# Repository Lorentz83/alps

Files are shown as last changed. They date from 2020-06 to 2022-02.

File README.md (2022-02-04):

# Another Light Painting Stick (ALPS)

This is just another programmable light painting stick.

But, compared to the other projects I've seen so far, instead of
storing all the settings on an SD card you can program the stick from
the phone.

WARNING: this is a work in progress and documentation may be not
         aligned with the current status of the code.

## TODO

An unordered list of stuff I'd like to work on:

- documentation:
  - add some example photos;
- on the board side:
  - re-add/improve SD card support;
- on the Android side:
  - re-design the whole app UI/UX (any help is appreciated);
  - add gradient/pattern generators;
  - write some unit test;

And most important:
- take many photos, enjoy the time spent, and find new features to implement :)

## Hardware

The following links are **not** affiliated. What follows is just a
list of stuff I bought and paid out of my pocket (well, technically
the Arduino was a birthday present from friends, but you know what I
mean).

For sure there are alternative products I'm not aware. If you know any
that may work better, please let me know.

- USB power bank;
- [Adafruit NeoPixel](https://learn.adafruit.com/adafruit-neopixel-uberguide/)
  144 LEDs 1 meter strip;
- HC-05 or HC-06 Bluetooth module;
- a capacitor between 500 and 1000 µF at 6.3 Volts or higher[^1];
- a resistor between 300 to 500 Ohm[^1];
- some USB cable to salvage;
- (Arduino Mega ADK)[https://docs.arduino.cc/retired/boards/arduino-mega-adk-rev3]
  or equivalent;
  - 1K resistor;
  - 2K resistor;
- or (Teensy 4.0)[https://www.pjrc.com/store/teensy40.html] which is
  more expensive than Arduino but faster.
  - [74AHCT125 quad level shifter](https://www.adafruit.com/product/1787)

I power everything using a 10400mAh USB power bank. There are a couple
of issues to keep in mind when using USB power banks for this project:

1. some power banks may disconnect the power if they see that there is
   too little usage (in other words, when the LED strip is off);
2. USB power banks usually limits the current at 2A (following the USB
   standard). At full brightness white, 144 NeoPixels consumes more
   than 8A[^1]. In practice that's probably too much light if you want
   to light paint.

More experiments using lithium batteries are needed, the power bank
has the benefit of simplicity because it doesn't require any voltage
regulator.

On the board side, not a lot of connectors are required. I suspect
that pretty much any programmable microcontroller could work as long
as you can load Arduino code on it.

My only suggestion is to be sure that it has at least a second
hardware serial to connect the bluetooth module.
It is not strictly required, but having the USB serial free is useful
to write debug messages, and I noticed that the software serial
library is usually not reliable enough for this project.

About the bluetooth module, the HC-05 may be faster (but if you can
find a good datasheet to prove it please let me know). But since we
don't need master mode the HC-06 can be good enough.

About the NeoPixels, I use the 144 LED for 1 meter. It is possible to
get less dense strips, but the result is much more pixelated.
Some code change is required if you want to support more than 144 LEDs.

The connections are pretty easy, but there are serious differences
between using Arduino or Teensy because Arduino is a 5V board while
Teensy is a 3v board.

WARNING: In both the cases the LED strip **cannot** be powered from
         the board because it drains far too much current.  If you
         power the board from a different source (for example the
         computer, when you connect it to load new code), it is
         important to share the ground. Also, don't put current on the
         NeoPixel data pin unless the NeoPixel is powered too[^1].
         In doubt, always disconnect the extra power and the whole LED
         strip while connecting the board to the computer.

The capacitor is used to smooth current peaks, according to the
NeoPixel guide[^1] it is mostly required if you power it from a bench
transformer, but it doesn't hurt to keep it there in any case to give
the extra power in case of brief spikes.

The resistor on the NeoPixel data pin should protect the 1st
pixel[^1]. It should be as close as the LED as possible.

TX and RX pin between the bluetooth module and the board are crossed
because the transmission of one goes to the receiving pin of the
other.

### Arduino

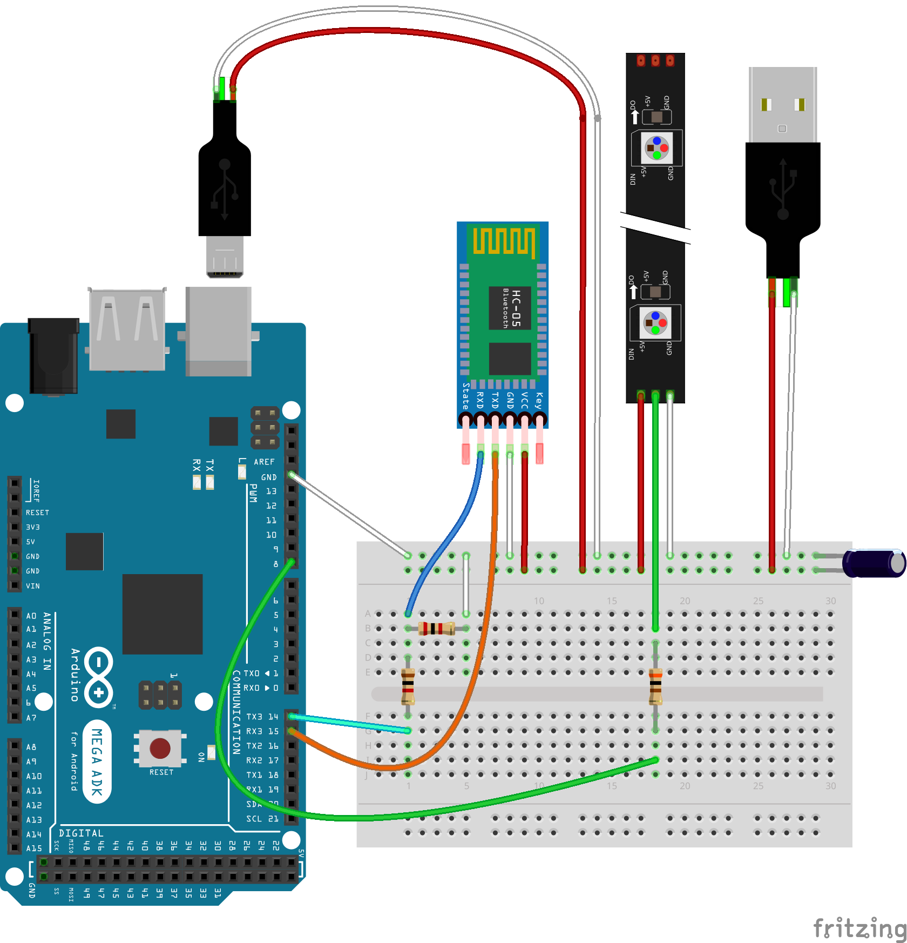
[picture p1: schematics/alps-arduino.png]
schematic


Arduino can be powered with 5V only from the USB cable, here it is
good if you have an old cable around to cut.

Remember that the bluetooth module data pin is 3.3V only. Therefore
you need the 2 resistors to lower down the 5V arduino output. The 1K
resistor between the arduino TX pin and the bluetooth RX pin, and the
2K resistor between the bluetooth RX pin and the ground.

The cable between the ground pin and the ground power is not required
in this configuration because the ground is already connected through
the USB cable.
But it is required if you power the board from the computer while the
LED strip is powered from the battery. Since this extra connection
doesn't hurt in any case, I strongly suggest to keep it always in
place.

### Teensy 4.0

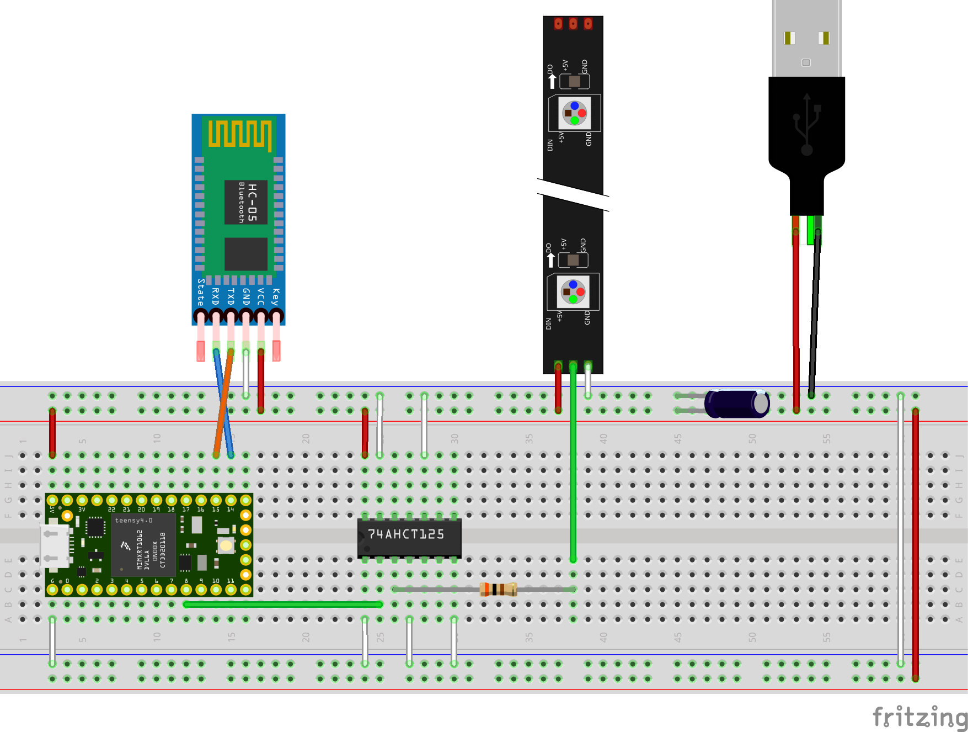
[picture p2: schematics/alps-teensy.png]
schematic


Being a 3V board, the Teensy can be powered from 5V through the 5V
pin.

WARNING: remember to remove the cable to the 5v pin if you connect the
         Teensy via USB to the computer while the LED are
         powered. Otherwise you may damage your computer.

The 74AHCT125 is used to send 5V signals to the NeoPixel data pin from
the 3V output. It is not always required, according to many websites
newer LED strips works with a 3V input too. But I noticed some
glitches without it, especially using the FastLED library.

Most of the connections around the 74AHCT125 are required only because
"all unused inputs of the device must be held at VCC or GND to ensure
proper device operation"[^2].

[^1]: https://learn.adafruit.com/adafruit-neopixel-uberguide/powering-neopixels
[^2]: https://www.ti.com/lit/ds/symlink/sn74ahct125.pdf

## License

This program is free software. The code I wrote is under GPL but some
of it depends on libraries under different (but compatible) license.
In doubt check the header of the specific files.

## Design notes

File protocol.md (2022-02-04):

# Protocol

Let's try do document a little the communication protocol between the
host (currently the Android app) and the client (the stick,
implemented by the Arduino or Teensy).
So that I can capture some of the design choiche and avoid reverse
engineering it next time I need to change it.

Requirements:
- Live show, sending a image and display it in real time;
- Info, to validate the software version;
- Reset, to re-synchronize the protocol;

Nice to have:
- Upload, send an image to the internal memory;
- Reshow, display an image from the internal memory;
- Reshow settings, to change brightness, delay, and loop option of the
  reshow;

In V1 the maximum image size I ever experimented with was 868x144;

WARNING: I don't plan to bump version numbers until I feel that the
         software is out of beta.

## V2

Protocol limitation:
- the number of LEDs must fit into a byte (255 max)
- the number of columns we can transfer in a single message must fit
  into a byte too.
- there is no escape sequence, if some bytes are lost the host needs
  to attempt to re-synchronize the communication before suggesting to
  turn off and on the client again.

All messages are initiated by the host. The host must wait for the
answer (or a reasonable timeout) before sending a new message.

The client can either acknowledge the message or return an error.
Both messages are 5 bytes long.

The acknowledgment message (ack in the future) is:
- ascii 'o', as in ok.
- 4 bytes of crc32 in little endian (least significant byte first).

The crc32 includes everything starting from the last message
identifier sent from the host.

The error message (nack in the future) is:
- ascii 'k', as in ko.
- 4 bytes to identify the error.

Before generating the error the stick should discard all the incoming
data over the wire. This is because, without having an escape
sequence, we cannot distinguish a valid message marker by a random
pixel color.

The plan is to document the error codes in the Arduino code in a
machine parsable, and write a script to extract them and generate a
map consumable by java. I didn't reach this point yet.

The client generates an error if it gets an invalid message marker, or
a message that is invalid for the current internal status.

### Host initiated messages

*info*

This is the only message that doesn't get an ack or a nack as answer.
It should be used when the connection is established so that host and
client can agree on the protocol version and exchange information
about the hardware.

The host sends a single byte '?'.

The client answers with 5 bytes:
0. the ascii '!'
1. a byte that should be interpreted as a bitset which describes the
   features enabled (so far nothing is supported, the idea is to use a
   bit to define if the stick has an SD card).
2. reserved for future use, shouldn't be validated by this version of
   the protocol.
3. the number of LEDs in the stick (unsigned int).
4. the maximum number of columns we can send in a single message
   (unsigned int).

The host should disconnect and raise an error message if it doesn't
support this version or doesn't recognize the message.

*new image*

It is used to start sending a new image for a live show.

The host sends the following bytes:
0. the ascii 'n' as in new image.
1. the number of pixels per column (unsigned int).
2. the delay in ms before showing the next column (unsigned int).
3. the number of columns sent in this message (must be at maximum what
   returned by info).
3. the pixels data in RGB (one byte per channel), for a total of
   columns * pixels * 3 bytes.

When a column is received the client takes care of rendering it.  It
should also take care of the delay as best effort (too much precision
is impossible because of delays in bluetooth communication and
slowness in updating the LEDs).

When all the data is received, and all the columns have been drawn on
the stick, the client sends the ack.
The host should verify the crc returned and raise an error if they
don't match.

The client can send a nack in case of validation errors of the header
data (example: too many pixels or columns) or if the data is not
received after a certain amount of time (currently 1 second, the
default timeout of Arduino read).

*continue image*

It is used to send the next batch of columns of an image.

The host sends:
0. the ascii 'c' as in continue.
1. lastMessage, a byte that evaluates to false if this is the last
   message for this image.
2. the number of columns to be sent (0 is a valid value).
3. pixels color in the same format as new image.

The client handles this message as the new image.

The only difference is that, if lastMessage is set to true, after
rendering the last column it waits the delay and turns off the stick.

*off*

Aborts the current operation and turns off the stick.
It can be used to re-sync the protocol in case an error happens.

The host sends:
- the ascii 'o' as in off.
- 4 random bytes.

The client answers with an ack.

If the host receives a nack or the crc returned doesn't match, the
host can assume some old message was on the wire and therefore can
retry sending another off.
Since the client must flush the buffer every time an error is
returned, the 2 should be able to re-sync eventually.

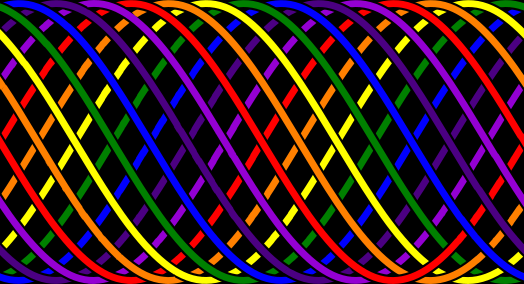
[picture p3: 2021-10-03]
resources/helix.png

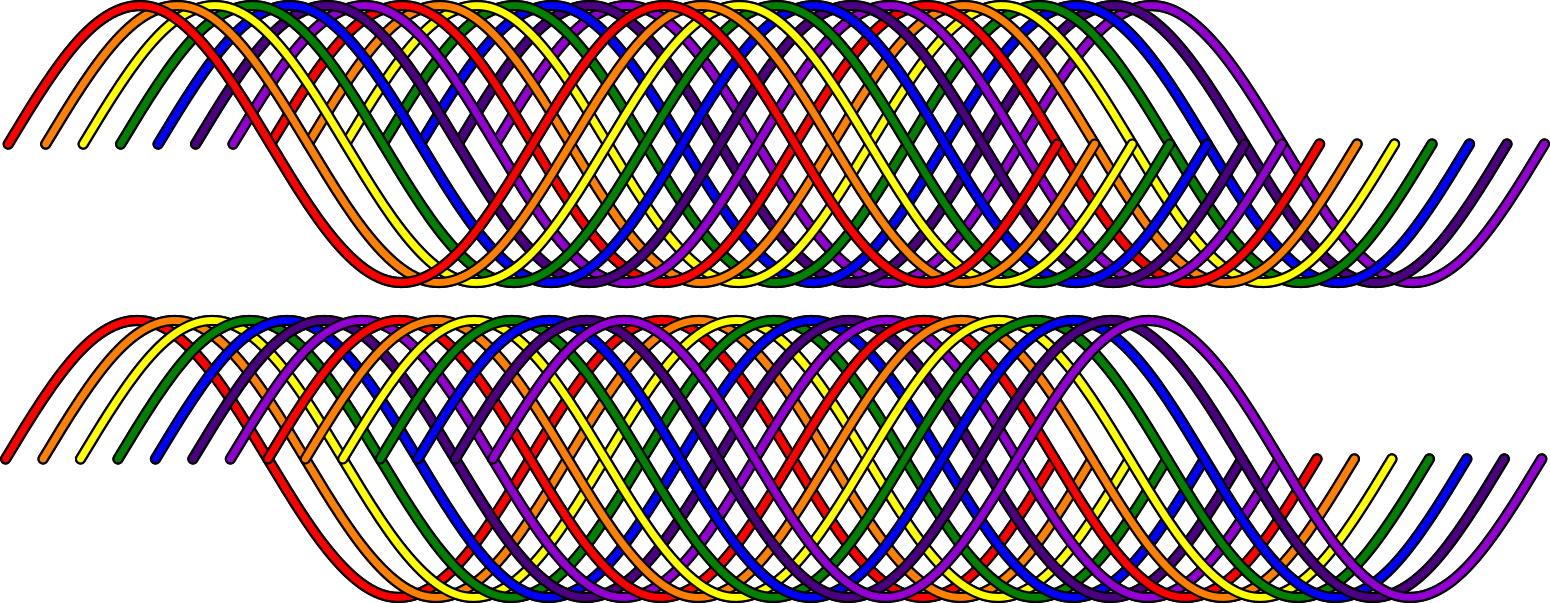
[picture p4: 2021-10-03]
resources/g3083.png

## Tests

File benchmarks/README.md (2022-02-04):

# Benchmarks

This directory contains a few benchmarks.

1. `ledspeed` measures how fast are different libraries in sending
   pixels.
2. `serialread` and `serialwrite` work in parallel to test the
   bluetooth connection.

NOTE: everything here is more like a scrapbook for me than an actual
product, to run the tests you have likely to touch the code to enable
some specific behaviours.  I tried to leave as many comments as
possible, but I may have failed.

## Findings

### LED libraries

Theoretically

> WS2812 strips are slow for writing data, with a data rate of just
> 800khz, it takes 30µs to write out a single led's worth of data[^1]

and they also need 300us reset time to wait after the whole strip is
written.[^2]

[^1]: https://github.com/FastLED/FastLED/wiki/Parallel-Output
[^2]: https://github.com/PaulStoffregen/WS2812Serial/issues/4

Therefore these are hard limits:
 - 4.32 milliseconds for a column, without wait (144 pixels)
 - 665 milliseconds for a square (144x144)
 - 1.3 seconds for a wide image (288x144)

In the `ledspeed` test, we simulate sending 10 times a 144x144 pixels
image, therefore the best we could get from this benchmark is 6.65
seconds, which is pretty much what we see with adafruit and DMA using
Tennsy 4.

NOTE: in this kind of tests we cannot measure the time on arduino
because `millis()` is not incremented when interrupts are disabled
([ref](https://forum.arduino.cc/t/does-nointerrupts-disable-the-millisecond-timer/433292/9)).

It is still interesting to measure it because it gives us an
estimation of how much time is spent in not sending data, which should
be processing and waiting to reset.

The 3 libraries compared are:
1. [Adafruit_NeoPixel](https://adafruit.github.io/Adafruit_NeoPixel/html/index.html)
2. [FastLED](https://github.com/FastLED/FastLED)
3. [WS2812Serial](https://github.com/PaulStoffregen/WS2812Serial) (Teensy only)

NOTE: in the following tables I report single round of tests. Also,
the millis and the wall time we see on the same line refers to
different runs. But you can check the comments in the source code and
see that there was not too much variance across different runs.

The time recorded here is about rendering 10 times a 144x144px image.

On Arduino Mega ADK

| Library | Wall time (s) | Millis |
| --- |---:| ---:|
| FastLED | 8.405086106 | 8542 |
| Adafruit  | 7.213265824 | 2470 |

On Teensy 4.0

| Library | Wall time (s) | Millis |
| --- |---:| ---:|
| FastLED | 7.728041386 | 7724 |
| Adafruit | 6.715214155 | 1920 |
| WS2812Serial | 6.649549581 | 6649 |

Sending a plain image generated completely on board, the Adafruit
library is the fastest and most portable option.

FastLED is slower, but we see that wall time is very close to
millis. Does it mean that it doesn't disable interrupts?  For sure its
timing is reset timing is buggy on Teensy because we have to add a
[delay](https://www.reddit.com/r/FastLED/comments/r9pq6o/odd_behaviors_on_teensy4_using_fastled/)
to make it work.
Testing in a real case scenario will follow, but so far I fear that
the "fast" in the name refers mostly to the "functions for
high-performing 8bit math for manipulating your RGB values", which is
not very useful in this project because pretty much all the processing
is done in the Android companion app.

### Serial

I really struggle to find the bluetooth boards datasheets, but according to
[this](http://www.techbitar.com/uploads/2/0/3/1/20316977/hc-05_at_commands.pdf) HC-05
can reach 1.382.400 bauds.
While HC-06 can either reach 115.200 bauds
([soruce](https://www.keuwl.com/electronics/rduino/bluet/09-baud-rate/))
or 1.382.400 bauds too
([source](http://www.martyncurrey.com/arduino-and-hc-06-zs-040/)).

It looks that Arduino Mega ADK can handle up to 230.400 bauds on the
USB serial. After data gets totally corrupted. It is a pretty old
board, so probably there are faster Arduino on the market nowadays.
While Teensy 4.0 can handle reasonably well 2.500.000 bauds.

Said so, all the tests with Arduino Mega ADK are done with an HT-06
module configured at 115200 bauds, while the tests with Teensy 4.0 are
done with an HT-05 module at 1382400 bauds.

### Bluetooth

`serialread`, in the basic usage, just reads on Arduino from
bluetooth, computes a crc and sends it back. Optionally, it can use
the a pixel library to send data to the LEDs.

`serialwrite` is a simple go code which writes on a serial device,
checks the returned crc and measures the time. It is written in GO
therefore it doesn't use the Android's Java stack. I'm not sure how
much performance difference it can introduce, but iterating over GO
code is much faster than over Android development.

NOTE: the protocol used here is different than the one used in the
main app, mostly for the sake of simplicity. Instead of sending an
header specifying how much data will follow, '\n' is handled as escape
sequence to trigger the answer from the controller. This is why
`serialwrite` changes every newline in the randomly generated data
stream to something else.

The first interesting finding is that there is a HUGE difference
between the non-blocking `Serial.read()` and the blocking
`Serial.readBytes()` IF the buffer is not always fully read.

This is because `readBytes` waits for 1 second timeout
([ref](https://www.arduino.cc/reference/en/language/functions/communication/serial/settimeout/))
before returning if it doesn't have enough data to fill the buffer.

In this setup, where the terminator byte is sent alone but we read
bytes 3 by 3 to get a full pixel, if we send the column one by one we
end up having an extra second delay on each column! Increasing the
chunk of data we can see the 2 functions converging in performances.

Checking the production code, it looks that every time `readBytes()`
returns a number of bytes different than the one asked it is because
we are on an error path.
But I spent probably half an hour trying to understand why the test
code was so slow before realizing it.
Also I cannot exclude for certain that using the blocking function
doesn't degrade performances even if we have enough data waiting in
the buffer.  It is probably better checking again and try to migrate
as much code as possible to use the non blocking `read()`.

The second investigation focused on finding the optimal amount of data
to send in a single write to maximize the throughput.
Again, I fail to find the optimal size of a bluetooth frame on
Internet, so let's test it.

All the following tests simulate to send images 144x10px in RGB.
It is read using the non-blocking Seria.read().
They just change how frequently the escape sequence is sent to trigger
and wait for the ack and the CRC.
The throughput measured here doesn't take into consideration the
escape sequences nor the acknowledgments.

Arduino Mega ADK, 115.200 baud.

| Chunk of data | time (s) | throughput (bit/s) |
| --- |---:| ---:|
| single pixels | 51.16 | 675.59 |
|  1 column | 0.76 | 45568.72 |
|  2 columns | 0.57 | 60376.26 |
|  3 columns | 0.50 | 69462.59 |
|  4 columns | 0.42 | 82051.10 |
|  5 columns | 0.45 | 76846.08 |
|  6 columns | 0.29 | 120223.26 |
|  7 columns | 0.33 | 104759.74 |
|  8 columns | 0.37 | 94039.08 |
|  9 columns | 0.40 | 85359.54 |
| 10 columns | 0.42 | 83067.11 |

Teensy 4.0, 1.382.400 baud.

| Chunk of data | time (s) | throughput (bit/s) |
| --- |---:| ---:|
| single pixels | 52.67 | 656.14 |
|  1 column | 0.42 | 81320.88 |
|  2 columns | 0.27 | 125687.88 |
|  3 columns | 0.20 | 169951.16 |
|  4 columns | 0.18 | 189385.55 |
|  5 columns | 0.23 | 150442.04 |
|  6 columns | 0.16 | 217615.06 |
|  7 columns | 0.15 | 234332.13 |
|  8 columns | 0.19 | 185802.02 |
|  9 columns | 0.19 | 185508.87 |
| 10 columns | 0.20 | 171838.52 |

We can see in both the cases that sending each pixel is terribly slow
because we incur in a lot of overhead (more acks) and also we likely
have mostly empty bluetooth frames.

We can see that Teensy is a not even twice as faster, despite having
the bluetooth module configured to go 10 time faster.

Again, without a real datasheet it is difficult to know for sure. But,
according to a few stores, HC-05 should implement Bluetooth 2.0 + EDR,
which should offer 2.1 Mbit/s of transfer speed
([Wikipedia](https://en.wikipedia.org/wiki/Bluetooth#Bluetooth_2.0_+_EDR)).
But here we see barely 230Kbit/s.
Which is 230.000 bauds, much lower than the 1.382.400 the module is set.

Honestly, I feel that the bluetooth protocol is terribly complex and
I'm not even sure which bluetooth version my laptop supports. I just
accept this data and make a mental note that it may be interesting to
test with a BLE module in the future.

Anyhow, sending data in columns is more reasonable and in both cases
we get the highest throughput between 6 and 7 columns (around 2800
bytes). The issue is that if we spend time to elaborate the column of
data (like sending it to the LED stick) we likely wait too much and we
drop data from the serial buffer.

### Combining together

The final step is to extend `serialread` to use all the LED libraries
and test how they behave on a real case.

Testing sending fractions of 144x144 image in single columns.
The Dummy library does nothing, it is just used to have a baseline
without LED overhead.

The time information here is expressed in seconds. I register a single
execution for simplicity, but I can say that with the double size
image I can see up to 1 second of variance.

Arduino Mega ADK

| Library |  1/4 |  1/2 | Full  | Double |
| --- |-----:|-----:|---:|---:|
| Dummy | 2.58 | 5.36 | 10.46 |  20.63 |
| Neopixel | 2.67 | 5.12 | 10.54 |  21.16 |
| FastLED | 2.57 | 5.29 | 10.76 |  20.96 |
| WS2812Serial |  n/a |  n/a | n/a | n/a |

Teensy 4.0

| Library |  1/4 |  1/2 | Full | Double |
| --- |-----:|-----:|-----:|---:|
| Dummy | 1.50 | 3.18 | 6.29 |  12.56 |
| Neopixel | 1.51 | 3.05 | 6.25 |  12.55 |
| FastLED | 1.50 | 3.06 | 6.24 |  12.50 |
| WS2812Serial | 1.57 | 3.17 | 6.35 |  12.66 |

Which looking at this doesn't really make any difference, the slowest
part remains the bluetooth.

Both the Neopixel and the FastLED library are too slow in rendering
the column (this is like the hardware limit of the LED strip), and
therefore if we try to send multiple columns we end up with data
corruption.

But since the `WS2812Serial` uses DMA, we don't use pretty much any
CPU cycle to send the data, therefore we can send as much as 6 columns
before we fill the buffer and we get data loss!
On the other side, the image is not rendered really smoothly anymore
because we add some extra delay every 6 columns.

Specifically, using WS2812Serial to send a 144x144px image in multiple
columns we get these results.

| # of cols | time (s) |
|---:|---:|
| 1 | 6.14 |
| 2 | 4.08 |
| 3 | 2.97 |
| 4 | 2.66 |
| 5 | 3.26 |
| 6 | 2.91 |

Coincidentally, 6 columns are also the one that gives a better
bluetooth throughput. Therefore the result is astonishingly fast
taking pretty much half time.

Now, flashing back the current project to both the boards I can see
that it takes 8.30s for Teensy and 12.56s for Arduino to process a
144x144px image.

Again, the Bluetooth stack is different, but I really hope that a 1
year old Android phone has a better Bluetooth support than a 5+ years
old computer running Linux. Therefore I have almost 30% performances I
can increase just fixing the transmission protocol.

After it I can try to write some Teensy specific code which buffers
the image received over bluetooth while rendering it in parallel using
DMA. 
On Teensy rendering a 144x144px image takes 0.66s, and the fastest
transmission (6 columns) of the same image takes 3s.
Meaning that the bottleneck is still the Bluetooth. Therefore with a
reasonably big buffer, and some appropriate delays between columns, we
should be able to send and render the image in parallel.

# Android

Hacking the Android app to generate a 144x144 image like the `serialwrite`, 
the best I can get is 7.30s, which is 1 second more than from the computer.
So I guess my expectation that the phone could handle bluetooth better
were wrong.
I also see a pretty big variance between different runs, I witnessed 1
second delays for no apparent reason.

More in detail:
 - Updating the progress bar doesn't waste any performance;
 - The `sleep(0)` to receive interrupts doesn't waste any time;
 - Also processing the bitmat doesn't seem to incur in any extra overhead;

But logging is terrybly slow. A single log line for each column adds a
good extra second on sending the image!

Also, restoring the original app (with the current protocol) has
similar performance once the logging instruction is removed.

At this point, there is no reason in try micro optimizations.
The only way to improve significantly the performance is to re-design
the protocol to allow sending more data in single writes, which likely
requires using the WS2812Serial library to save time on writing the LEDs.

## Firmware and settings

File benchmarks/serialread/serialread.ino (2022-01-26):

#include <CRC32.h>
#include <Adafruit_NeoPixel.h>
#include <FastLED.h>



// Switch this to Serial to test over USB instead of bluetoot
#define channel Serial3

#define debug(x) Serial.println(x)

const int led_pin = 6; 
const int led_pin_dma = 8; // Serial 2 on Teensy 4.0
const int numled = 144;


Adafruit_NeoPixel adafruit(numled, led_pin, NEO_GRB + NEO_KHZ800);

CRGB leds[numled]; // FastLED

#ifdef ARDUINO_TEENSY40

#include "WS2812Serial.h" // https://www.pjrc.com/non-blocking-ws2812-led-library/
byte drawingMemory[numled*3];         //  3 bytes per LED
DMAMEM byte displayMemory[numled*12]; // 12 bytes per LED
WS2812Serial dma_leds(numled, displayMemory, drawingMemory, led_pin_dma, WS2812_GRB);

#endif




struct DummyLibrary {
  void show() {
    // debug("show");
  };
  void setPixelColor(uint16_t, uint8_t, uint8_t, uint8_t) {
  }
} dummy;

struct FastLEDInterface {
  void show() {
    FastLED.show();
  };
  void setPixelColor(uint16_t n, uint8_t r, uint8_t g, uint8_t b) {
    leds[n].setRGB(r, g, b);
  }
} fastLEDWrapper;


void setup() {

  Serial.begin(115200);
  
#ifdef ARDUINO_TEENSY40
  Serial3.begin(1382400); // teensy
#else
  pinMode(15, INPUT_PULLUP);
  Serial3.begin(115200); // arduino
#endif

  adafruit.begin();
  
  FastLED.addLeds<WS2812, led_pin, GRB>(leds, numled);  // WS2812B?

  #if defined(ARDUINO_TEENSY40)
  dma_leds.begin();
  #endif
}


void loop() {
  // NOTE Only one of the following should be uncommented.
  
  // readOnly();
  // readOnlyBy3();

  // These requires the terminator to be aligned at the column.
  simulate(dummy);
  // simulate(adafruit);
  // simulate(fastLEDWrapper);
  // simulate(dma_leds); // Only with tennsy
  // simulateMultiCol(dma_leds); // Only with tennsy
}


CRC32 crc;
uint32_t num = 0;
byte buf3[3];
size_t bufIdx = 0;

#if defined(ARDUINO_TEENSY40)
void simulateMultiCol(WS2812Serial& library) {
  if ( channel.available() > 0 ) {
    byte b = channel.read();
    crc.update(b);
    num++;
    if (b == '\n' ) {
      uint32_t checksum = crc.finalize();
      crc.reset();
      // No show, here we assume we always get full columns, so we don't show twice.
      writeUInt32(num);
      writeUInt32(checksum);
      num = 0;
      bufIdx = 0;
    } else {
      buf3[bufIdx++] = b;
      if ( bufIdx == 3  ) { // we have a full pixel
        bufIdx = 0;
        int px = num/3 - 1; // zero index.
        px = px % numled;
        library.setPixelColor(px, buf3[0], buf3[1], buf3[2]);
        if (px == numled - 1) {
          library.show(); // with DMA this should be close to no time.
        }
      }
    }
  } 
}
#endif

template<class T>
void simulate(T& library) {
  if ( channel.available() > 0 ) {
    byte b = channel.read();
    crc.update(b);
    num++;
    if (b == '\n' ) {
      uint32_t checksum = crc.finalize();
      crc.reset();

      library.show(); // must be called AFTER reading the escabe but BEFORE sending the ack.
      
      writeUInt32(num);
      writeUInt32(checksum);
      num = 0;
      bufIdx = 0;
    } else {
      buf3[bufIdx++] = b;
      if ( bufIdx == 3  ) { // we have a full pixel
        bufIdx = 0;
        int px = num/3 - 1; // zero index.
        if ( px > numled ) {
          debug("ERROR pixel");
          debug(px);
        } else {
          library.setPixelColor(px, buf3[0], buf3[1], buf3[2]);
        }
      }
    }
  }
}

void readOnlyBy3() {
  size_t r = channel.readBytes(buf3, 3);
  // Here if r == 1 we have the terminator and we wait 1 full second before moving on.
  for ( size_t i = 0 ; i<r ; i++ ) {
    num++;
    crc.update(buf3[i]);
    if (buf3[i] == '\n' ) {
      uint32_t checksum = crc.finalize();
      crc.reset();
      writeUInt32(num);
      writeUInt32(checksum);
      num = 0;
    }
  }
}

void readOnly() {
  if ( channel.available() > 0 ) {
    uint8_t b = channel.read();
    crc.update(b);
    num++;
    if (b == '\n' ) {
      uint32_t checksum = crc.finalize();
      crc.reset();
      writeUInt32(num);
      writeUInt32(checksum);
      num = 0;
    }
  }
}

void writeUInt32(uint32_t val) {
    for ( int i = 0 ; i<4 ; i++) {
      channel.write(val & 0xFF);
      val = val >> 8;
    }
}

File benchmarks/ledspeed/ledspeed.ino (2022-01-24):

#include <Adafruit_NeoPixel.h>
#include <FastLED.h>


#define testMillis // comment this to measure time from PC. Use `cd timer && go run timer.go`


const int led_pin = 6; 
const int led_pin_dma = 8; // Serial 2 on Teensy 4.0
const int numled = 144;


Adafruit_NeoPixel pixels(numled, led_pin, NEO_GRB + NEO_KHZ800);

CRGB leds[numled];


#ifdef ARDUINO_TEENSY40

#include "WS2812Serial.h" // https://www.pjrc.com/non-blocking-ws2812-led-library/
byte drawingMemory[numled*3];         //  3 bytes per LED
DMAMEM byte displayMemory[numled*12]; // 12 bytes per LED
WS2812Serial dma_leds(numled, displayMemory, drawingMemory, led_pin_dma, WS2812_GRB);

#endif


void setup() {
  // Serial.begin(9600);
  Serial.begin(115200);

  FastLED.addLeds<WS2812, led_pin, GRB>(leds, 144);  // WS2812B?

  pixels.begin();

  #if defined(ARDUINO_TEENSY40)
  dma_leds.begin();
  #endif
}

#ifdef testMillis
#define printMillis() Serial.println(time)
#else
#define printMillis()
#endif

unsigned long time;
void loop() {
  
  Serial.print('f');
  time = millis();
  for (int i = 0; i<10; i++) slideFastLED();
  time = millis() - time;
  Serial.print('.');
  printMillis();

  Serial.print('a');
  time = millis();
  for (int i = 0; i<10; i++) slideAdafruit();
  time = millis() - time;
  Serial.print('.');
  printMillis();

  #if defined(ARDUINO_TEENSY40)

  Serial.print('d');
  time = millis();
  for (int i = 0; i<10; i++) slideDMA();
  time = millis() - time;
  Serial.print('.');
  printMillis();

  #endif
}

/*

WARNING: millis() is not incremented during the interrupt functions (https://www.arduino.cc/reference/en/language/functions/external-interrupts/attachinterrupt/).

Testing on Arduino MEGA ADK

with millis
f.8542
a.2470
f.8541
a.2469

Wall clock:
fastLED 8.405086106s
adafruit 7.213265824s
fastLED 8.392739761s
adafruit 7.212967165s


Testing it with Teensy, a logic level shifter is required otherwise the LED strip sometime behaves weirdly. 

Testing with millis let us know the time spent when intterrupts are enabled,
which should be the time spent while NOT using CPU to send data ~ time to process data + time to wait between columns.

f.7724
a.1920
d.6649

f.7724
a.1920
d.6649

f.7724
a.1920
d.6649


Checking the wall clock monitoring the serial port from the computer:

fastLED 7.728041386s
adafruit 6.715214155s
DMA 6.649549581s

fastLED 7.727930343s
adafruit 6.715443377s
DMA 6.649588857s

fastLED 7.728037941s
adafruit 6.715460754s
DMA 6.649607675s

fastLED 7.727986571s
adafruit 6.715514328s
DMA 6.649302187s

fastLED is the slowest option on Teensy, which is probably because we have to add the delay(1) in the loop.
Which means that in a real case scenario where we have to spend time between reading columns it may be faster.
But it cannot be faster than DMA where we see that time millis is pretty much the same wall clock we measure,
meaning that we don't use CPU at all and we can spend all that CPU time doing other stuff.

After this, the only further improvement is to split the LED strip in 2 and try 
1. Parallel output https://github.com/FastLED/FastLED/wiki/Parallel-Output

Theoretically, according to https://github.com/FastLED/FastLED/wiki/Parallel-Output:
> WS2812 strips are slow for writing data, with a data rate of just 800khz, it takes 30µs to write out a single led's worth of data. 
and from https://github.com/PaulStoffregen/WS2812Serial/issues/4
> wait 300us WS2812 reset time

Therefore these are hard limits:
 - 4.62 milliseconds for a column (144 pixels)
 - 665 milliseconds for a square (144x144)
 - 1.3 seconds for a wide image (288x144)

The test sends 10 144x144 images, therefore the best we could get from this benchmark is 6.65 seconds,
which is pretty much what we see with adafruit and DMA using tennsy 4.

 */


#if defined(ARDUINO_TEENSY40)
void slideDMA() {
  for ( int x = 0 ; x < numled ; x++ ) {
    for ( int y = 0 ; y < numled ; y++ ) {
        int pos = (x - y) % numled;
        dma_leds.setPixelColor(y, pos == 0 ? 50 : 0, pos == 5 ? 50 : 0, pos == 10 ? 50 : 0);
    }
    dma_leds.show();
  }  
}
#endif

void slideFastLED() {
  for ( int x = 0 ; x < numled ; x++ ) {
    for ( int y = 0 ; y < numled ; y++ ) {
        int pos = (x - y) % numled;
        leds[y].setRGB(pos == 0 ? 50 : 0, pos == 5 ? 50 : 0, pos == 10 ? 50 : 0);
    }
    FastLED.show();
    #if defined(ARDUINO_TEENSY40)
    // Required on Teensy https://www.reddit.com/r/FastLED/comments/r9pq6o/odd_behaviors_on_teensy4_using_fastled/
    delay(1);
    #endif
  }  
}

void slideAdafruit() {
  for ( int x = 0 ; x < numled ; x++ ) {
    for ( int y = 0 ; y < numled ; y++ ) {
        int pos = (x - y) % numled;
        pixels.setPixelColor(y, pos == 0 ? 50 : 0, pos == 5 ? 50 : 0, pos == 10 ? 50 : 0);
    }
    pixels.show();
  }  
}

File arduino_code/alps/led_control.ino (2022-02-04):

/**
    Copyright 2020-2021 Lorenzo Bossi

    This file is part of ALPS (Another Light Painting Stick).

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
    You should have received a copy of the GNU General Public License
    along with ALPS.  If not, see <https://www.gnu.org/licenses/>.
*/


#ifdef DMA_LED
  #include "WS2812Serial.h" 
#else 
  #include <Adafruit_NeoPixel.h>
#endif

template<int maxPixels>
class LedControl {

#ifdef DMA_LED
  byte displayMemory[maxPixels*12]; // 12 bytes per LED
  byte drawingMemory[maxPixels*3];  //  3 bytes per LED
  WS2812Serial pixels;

public: 
  LedControl(uint16_t pin) : pixels(maxPixels, displayMemory, drawingMemory, pin, WS2812_GRB) {
  }
  
  bool busy() {
    return pixels.busy();
  }

#else 
  Adafruit_NeoPixel pixels;

public:
  LedControl(uint16_t pin) : pixels(maxPixels, pin, NEO_GRB + NEO_KHZ800) {
  }
  
  bool busy() {
    return !pixels.canShow();
  }

#endif

  void init() {
    pixels.begin();
  }

  void show() {
    pixels.show();
  }

  void fill(uint8_t r, uint8_t g, uint8_t b) {
    for ( int i = 0 ; i < maxPixels ; i++ ) {
        pixels.setPixelColor(i, r, g, b);
    }
  }

  void off() {
    fill(0, 0, 0);
    pixels.show();
  }

  void setPixelColor(uint16_t pos, uint8_t r, uint8_t g, uint8_t b) {
    pixels.setPixelColor(pos, r, g, b);
  }

  void flashError() {
    fill(100, 0, 0);
    pixels.show();
    delay(500);
    fill(2, 0, 0);
    pixels.show();
    delay(500);
    fill(100, 0, 0);
    pixels.show();
    delay(500);
    fill(2, 0, 0);
    pixels.show();
    delay(500);
    fill(100, 0, 0);
    pixels.show();
    delay(500);
    off();
  }

  void flashInit() {
    fill(2, 0, 0);
    pixels.show();
    delay(200);
    fill(0, 2, 0);
    pixels.show();
    delay(200);
    fill(0, 0, 2);
    show();
    delay(200);
    off();
  }

  uint16_t numPixels() const {
    return maxPixels;
  }

};

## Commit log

2020-06-13 Better communication protocol, fixed bluetooth connection.
    Fixes:
    - there was no time to enter the pin when pairing a new device
    - few tweks to the communication protocol
    - some code cleanup
    New features:
    - SD card support to cache the image and re-play it faster
    - added a button on the arduino to start re-play
    - added an "upload" button on the app to load the image on arduino
    - new window to config re-play settings
    - long tap on the image preview sends it to an external app for editing
2020-09-17 Fixed edit layout and made edit button following the same style of the others.
2021-09-14 Added a new testing helper to write integration tests between java and the c++ arduino protocol library
2021-10-03 Some fixes in the communication protocol.
    Arduino didn't break execution on error, so it was easier to go out of sync.
    It is not completely fixed, but the protocol is more robust now.
    [protocol.ino]
2021-10-03 Resource files added (original for buttons and images)
2021-12-16 First try to port everything on Teensy.
    Using a HC-05 bluetooth module I can set a much faster transfer rate.
    It is still slow, but there is probably room to improve the protocol for a better throughput.
    Also, Teensy has much more RAM (1024K) compared to the Arduino Mega (8k). I can investigate memory cache and asynchronous transfer.
    SD is disabled for now (no real technical reason, I'm just keeping the prototyping board cleaner). Hopefully there won't be need for it anymore.
    [alps.ino, init_bluetooth.ino, zmain.ino]
2021-12-21 The benchmark now can simulate sending data to the LEDs.
2021-12-22 fixed benchmark.
    It didn't call pixels.show() correctly. Now that it does I can see the missing bytes when more than 1 column of pixels is sent
    [serialread.ino]
2021-12-22 New benchmark to test FastLED library.
    For what I need it (just write LED colors and display them) FastLED is much slower than Adafruit library.
    But there are another couple of libraries to investigate for Teensy.
2022-01-24 Benchmark using the WS2812Serial library for Teensy
    Also fixed the benchmark (and the comments) which was running on wrong assumptions.
    [WS2812Serial.cpp, ledspeed.ino]
2022-01-29 Added schematics and documented the hardware used.
    [alps-arduino.fzz, alps-teensy.fzz]
2022-02-01 Completely new (unfinished) transmission protocol.
    This is the 1st step to implement a more efficient transmission which
    should benefit by the Teensy extra power but still being compatible
    with Arduino.
    It is not finished yet, there is no way it can work at the current
    status.
2022-02-01 Sending image fixes.
    Still not tested on the device, but the integration test now works.
    Also, there is no delay between columns yet.
    [protocol.ino]
2022-02-02 So many small fixes in the protocol that I honestly don't know how to enumerate them.
    It is still untested on the device, but now I'm a little more confident it may work.
    Also a few improvement in the testing framwork.
    [led_control.ino, protocol.ino]
2022-02-03 Tested on device!
    Fixed a couple of issues, now it can send the image and it looks good.
    Still no performance improvement and still a few missing features.
2022-02-03 Enabling the WS2812Serial library.
    On Teensy now I can trasfer a 144x144 image in less than 3 seconds!
    Compared to the 7 seconds is a HUGE improvement!
    Also, refactored a little better the code to support both Arduino and Teensy.
    Still, missing the delay between columns.
    [WS2812Serial.ino, alps.ino, led_control.ino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]
2022-02-04 Make rule to build both teensy and arduino code.
    Also few fixes in the readme in comments.
    [protocol.ino]
2022-05-09 Added options to use bilinear filter or anti aliasing when scaling images.
    Also, bumped gradle version.

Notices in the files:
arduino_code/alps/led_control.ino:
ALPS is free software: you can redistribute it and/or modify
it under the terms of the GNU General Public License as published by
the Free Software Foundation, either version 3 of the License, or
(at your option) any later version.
